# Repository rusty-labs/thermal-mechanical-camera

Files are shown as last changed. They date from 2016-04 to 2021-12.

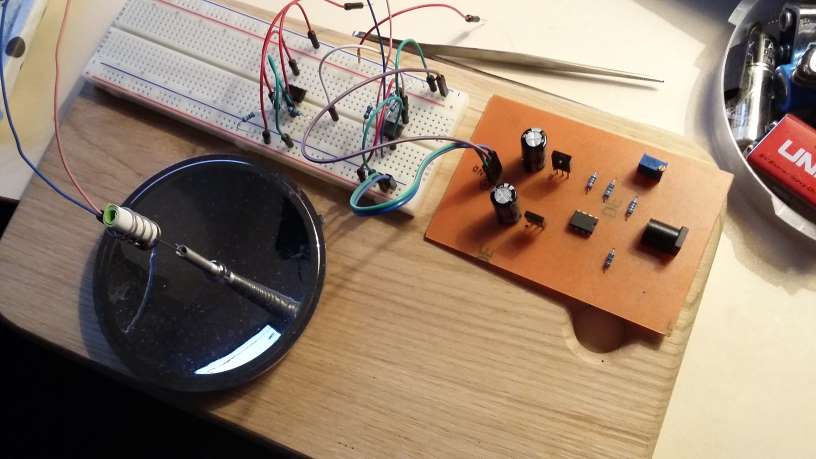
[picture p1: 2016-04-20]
scanner-photos/early_prototype001.jpg

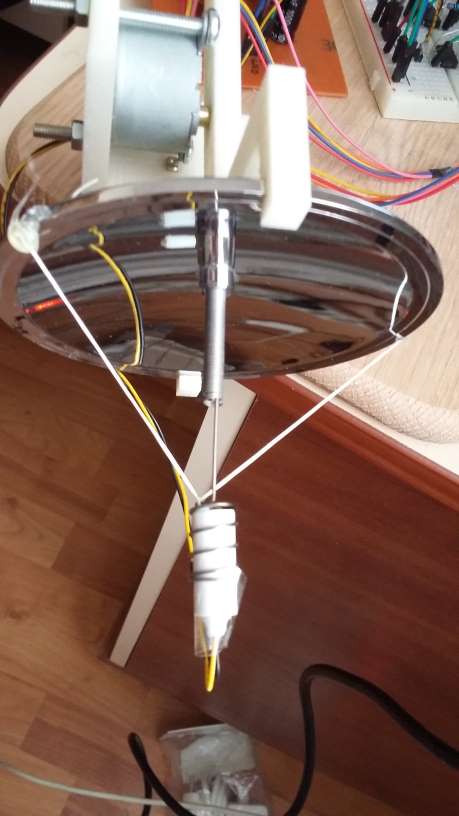
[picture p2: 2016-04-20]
scanner-photos/early_prototype002.jpg

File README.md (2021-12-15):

Building a cheap and simple thermal, mechanical camera.

Specs:
 Taking 400x200 image takes roughly 30 min. 

Hardware requirements:
 1. Metallized, parabolic mirror - "Survival Solar Lighter".
 2. 3D printed mounts for motors and mirror.
 3. Two stepper motors - 28byj-48, these motors will be used as bipolar motors.
 4. Two motor controllers based on L293D.
 5. Thermopile sensor:

   a) TS118, needs additional circuitry for amplifying the signal.
   
   b) MLX90614ESF, has circuitry inside so you don't need to create one (Recommended choice!).
   
 6. Amplifying circuitry, needed only if you're going to use TS118.
 7. Arduino
 8. MicroSD card module for arduino

Arduino code:

   a) For MLX90614ESF, this sensor returns temperature by I2C protocol.
   
   b) For TS118, this sensor returns analogue signal, which will be converted to temperature afterwards.

Overall cost - 25$.

Folders descriptions:

1. arduino\scanner - contains arduino code for running the scanning process.
2. circuits - contains circuits for stepper controller and signal amplification.
3. 3d-models - containts 3d models of mounts.
4. sample-images - contains thermal images.
5. scanner-photos - contains photos of a scanner.

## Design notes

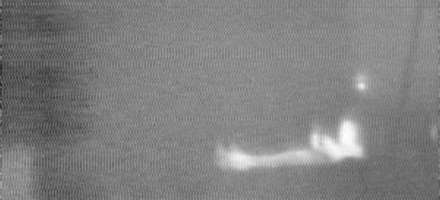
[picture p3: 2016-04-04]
sample-images/first image - reading book under lamp.jpg

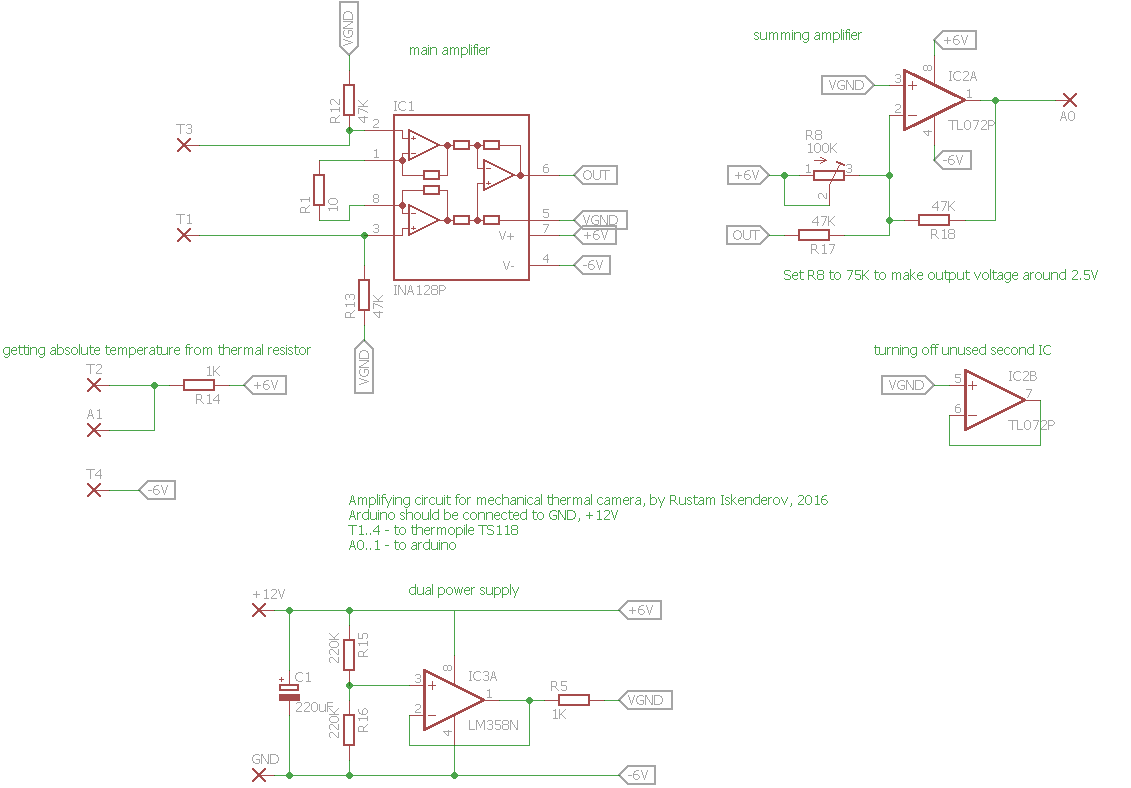
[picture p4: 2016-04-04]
circuits/Amplifying circuit for TS118.png

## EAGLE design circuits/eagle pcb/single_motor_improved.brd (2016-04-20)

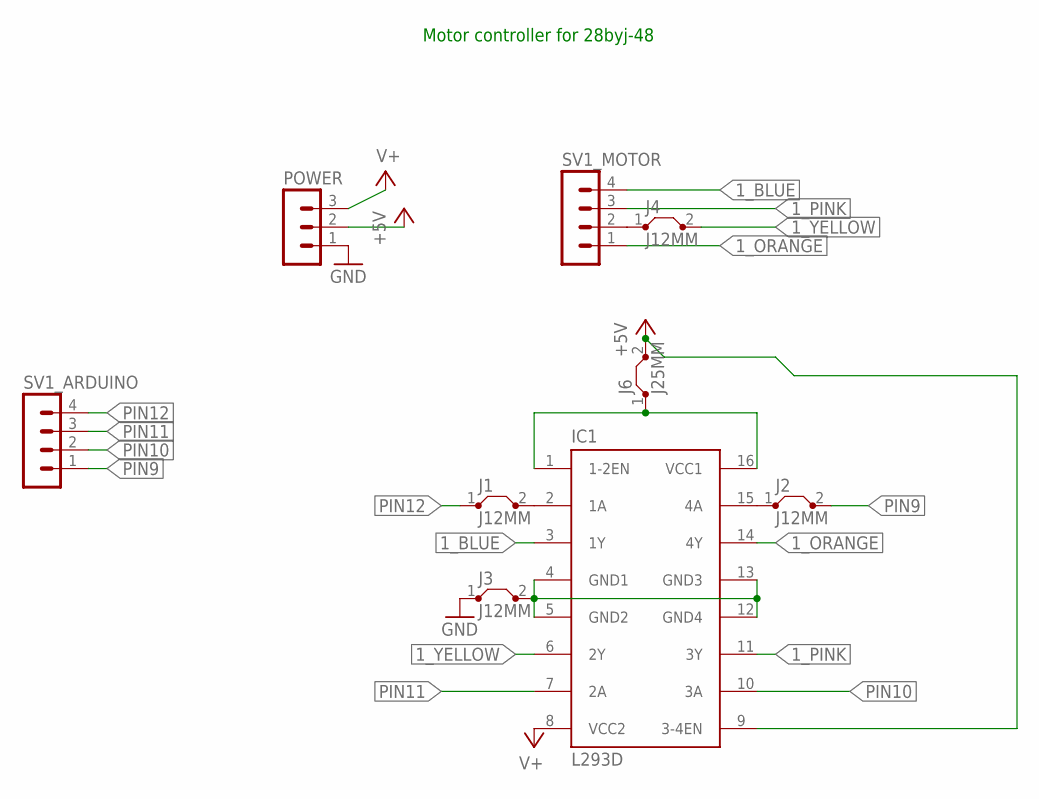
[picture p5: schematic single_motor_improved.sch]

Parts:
IC1: L293D; DIL16
J1, J2, J3, J4: J12MM; 12
J6: J25MM; 25
POWER: MA03-1
SV1_ARDUINO, SV1_MOTOR: MA04-1

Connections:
1_BLUE: IC1.3 (1Y), SV1_MOTOR.4
1_ORANGE: IC1.14 (4Y), SV1_MOTOR.1
1_PINK: IC1.11 (3Y), SV1_MOTOR.3
1_YELLOW: IC1.6 (2Y), J4.2
+5V: IC1.9 (3-4EN), J6.2, POWER.2
GND: J3.1, POWER.1
unnamed: IC1.2 (1A), J1.2
unnamed: IC1.15 (4A), J2.1
unnamed: IC1.1 (1-2EN), IC1.16 (VCC1), J6.1
unnamed: J4.1, SV1_MOTOR.2
unnamed: IC1.4 (GND1), IC1.5 (GND2), IC1.12 (GND4), IC1.13 (GND3), J3.2
PIN9: J2.2, SV1_ARDUINO.1
PIN10: IC1.10 (3A), SV1_ARDUINO.2
PIN11: IC1.7 (2A), SV1_ARDUINO.3
PIN12: J1.1, SV1_ARDUINO.4
V+: IC1.8 (VCC2), POWER.3

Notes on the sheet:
Motor controller for 28byj-48

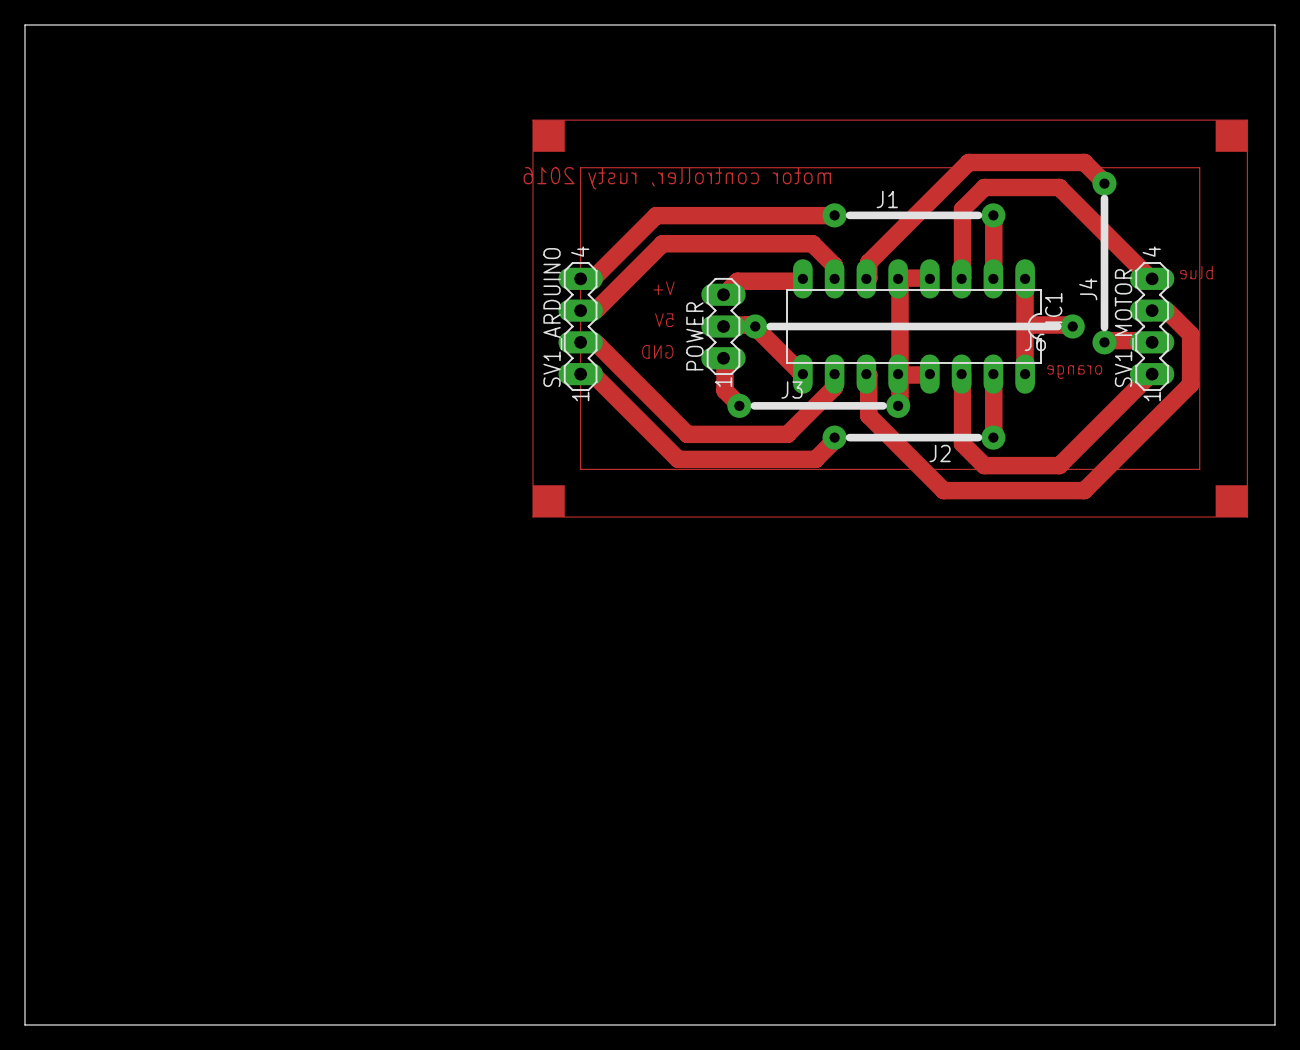
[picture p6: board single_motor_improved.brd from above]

Board: 2 copper layers, 100.0 x 80.0 mm, 9 parts (0 on the bottom side), 16 nets.

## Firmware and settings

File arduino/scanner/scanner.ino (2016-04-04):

#include <SPI.h>
#include <SD.h>

#define _DEBUG

#include "BasicMedianFilter.h"
#include "BitmapWriter.h"
#include "BasicStepper.h"


unsigned long last_time;
long time;

static const uint8_t SAMPLES_COUNT = 210;
BasicMedianFilter<uint16_t, SAMPLES_COUNT> m_temperature;


BasicStepper hStepper;
BasicStepper vStepper;
BmpWriter bmpWriter;

//const unsigned int H_SIZE = 4 * 110;
//const unsigned int V_SIZE = 4 * 50;

const unsigned int H_SIZE = 4 * 30;
const unsigned int V_SIZE = 4 * 20;

unsigned int v_pos = 0;
unsigned int h_pos = 0;
bool run_cycle = false;
bool finish_cycle = false;

unsigned long scanning_time = 0;


void setup()
{
  Serial.begin(9600);

  /*
  while (!Serial) {
    ; // wait for serial port to connect. Needed for Leonardo only
  }
  */
  if (!SD.begin(10)) {
    Serial.println("SD initialization failed!");
    return;
  }
  Serial.println("SD initialization done.");

  hStepper.init(5, 4, 3, 2);
  vStepper.init(A2, A3, A4, A5);

  hStepper.setDelay(0);
  vStepper.setDelay(0);
}


unsigned long time1;

uint16_t getTemperature()
{
  m_temperature.clear();

  uint32_t measurementTime = 20000 / SAMPLES_COUNT; // usec

  //  delayMicroseconds(18000);

  for (uint8_t i = 0; i < SAMPLES_COUNT; ++i)
  {
    uint32_t time1 = micros();
    m_temperature.add(analogRead(A0));

/*
    uint32_t time_spent = micros() - time1;

    if (time_spent < measurementTime)
    {
      delayMicroseconds(measurementTime - time_spent);
    }
*/
  }

  uint16_t _median;

  m_temperature.getMedian(_median);

    //m_temperature.getAverage(10, _median);
    //Serial.print("Median = ");
    //Serial.print(_median);
    //Serial.println(" ");


  return _median;
}

void startScanning()
{
  scanning_time = millis();

  char fileName[] = "output00.bmp";

  for (int i = 0; i < 100; ++i)
  {
    fileName[6] = i / 10 + '0';
    fileName[7] = i % 10 + '0';

    if (!SD.exists(fileName))
    {
      break;
    }
  }

  if (bmpWriter.create(fileName, H_SIZE, V_SIZE, 8) == false)
  {
    return;
  }

  bmpWriter.fillEmptyData();

  //delay(20000);

  run_cycle = true;
}


void stopScanning()
{
  finish_cycle = true;
}

void loop()
{
  /*
    time1 = micros();
    getTemperature();
    //Serial.println(micros()-time1);

    delay(300);

    return;
  */


  if (Serial.available())
  {
    int cmd = Serial.parseInt();

    switch (cmd)
    {
      case 0:
        stopScanning();
        break;

      case 2:
        vStepper.stepsAsync(4 * 5);
        vStepper.resetLastDir();
        break;

      case 3:
        vStepper.stepsAsync(-4 * 5);
        vStepper.resetLastDir();
        break;

      case 4:
        hStepper.stepsAsync(4 * 5);
        hStepper.resetLastDir();
        break;

      case 5:
        hStepper.stepsAsync(-4 * 5);
        hStepper.resetLastDir();
        break;

      case 9:
        startScanning();
        break;
    }

  }

  if (run_cycle)
  {
    if (hStepper.getState(BasicStepper::RUN) == false)
    {
      bmpWriter.flush();
      // moving to the next horizontal line
      vStepper.step(true);

      Serial.print("vertical pos: ");
      Serial.println(v_pos++);

      if (hStepper.getState(BasicStepper::LAST_DIR_FORWARD))
      {
        //going backward
        hStepper.stepsAsync(-H_SIZE);
        h_pos = H_SIZE - 1;
      } else
      {
        //going forward or stop

        h_pos = 0;

        if (finish_cycle)
        {
          bmpWriter.close();
          run_cycle = false;
          finish_cycle = false;
          vStepper.stepsAsync(-v_pos);
          v_pos = 0;
        } else
        { // new horizontal cycle

          if (v_pos > V_SIZE)
          { //scanning is finished
            bmpWriter.close();
            run_cycle = false;
            vStepper.stepsAsync(-v_pos);
            v_pos = 0;

            Serial.print("finished, scanning time, sec: ");
            Serial.println((millis() - scanning_time) / 1000);

          } else {
            hStepper.stepsAsync(H_SIZE);
          }

        }// end horizontal cycle

      }

    } else
    {
      if (v_pos <= V_SIZE)
      {
        uint32_t clr = (uint32_t(255) * getTemperature()) / 1023;

        // Serial.print("clr: ");
        // Serial.println(clr);

        bmpWriter.writePixel(h_pos, v_pos - 1, clr);

        if (hStepper.getState(BasicStepper::LAST_DIR_FORWARD))
        {
          ++h_pos;
        } else
        {
          --h_pos;
        }
      }


    }
  }

  hStepper.work();
  vStepper.work();
}

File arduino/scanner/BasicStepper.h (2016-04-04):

/*
 Created by Rustam Iskenderov, 2016
 For mechanical thermal imaging camera
*/


/*
 Simple way to control stepper motor
*/

class BasicStepper
{
  public:

    static const uint8_t RUN = 0x1;
    static const uint8_t LAST_DIR_FORWARD = 0x2;
    static const uint8_t LAST_DIR_BACKWARD = 0x4;

    void init(uint8_t pin0, uint8_t pin1, uint8_t pin2, uint8_t pin3)
    {
      _pin0 = pin0;
      _pin1 = pin1;
      _pin2 = pin2;
      _pin3 = pin3;

      reset();
      resetLastDir();

      _delay = 30000;

      pinMode(_pin0, OUTPUT);
      pinMode(_pin1, OUTPUT);
      pinMode(_pin2, OUTPUT);
      pinMode(_pin3, OUTPUT);

      digitalWrite(_pin0, LOW);
      digitalWrite(_pin1, LOW);
      digitalWrite(_pin2, LOW);
      digitalWrite(_pin3, LOW);
    }

    void setDelay(unsigned long delay)
    {
      _delay = delay;
    }

    void reset()
    {
      _coilIdx = 0;
      _steps = 0;
      setState(RUN, false);
    }

    void resetLastDir()
    {
      setState(LAST_DIR_FORWARD | LAST_DIR_BACKWARD, false);
    }


    void step(bool forward)
    {
      switch (_coilIdx) {
        case 0:
          digitalWrite(_pin0, LOW);
          digitalWrite(_pin1, HIGH);
          digitalWrite(_pin2, HIGH);
          digitalWrite(_pin3, LOW);
          break;
        case 1:
          digitalWrite(_pin0, LOW);
          digitalWrite(_pin1, HIGH);
          digitalWrite(_pin2, LOW);
          digitalWrite(_pin3, HIGH);
          break;
        case 2:
          digitalWrite(_pin0, HIGH);
          digitalWrite(_pin1, LOW);
          digitalWrite(_pin2, LOW);
          digitalWrite(_pin3, HIGH);
          break;
        case 3:
          digitalWrite(_pin0, HIGH);
          digitalWrite(_pin1, LOW);
          digitalWrite(_pin2, HIGH);
          digitalWrite(_pin3, LOW);
          break;
        default:
          park();
          break;
      }

      if (forward)
      {
        _coilIdx++;
      } else
      {
        _coilIdx--;
      }

      if (_coilIdx > 3)
      {
        _coilIdx = 0;
      }

      if (_coilIdx < 0)
      {
        _coilIdx = 3;
      }

      delayMicroseconds(_delay);
    }

    void stepsAsync(int16_t steps)
    {
      setState(RUN);
      _steps = steps;
      
      resetLastDir();
      
      if (steps > 0)
      {
        setState(LAST_DIR_FORWARD);
      } else
      {
        setState(LAST_DIR_BACKWARD);
      }
    }

    void work()
    {
      if (getState(RUN))
      {
        int8_t dir = _steps > 0 ? -1 : 1;

        if (_steps != 0)
        {
          step(_steps > 0 ? true : false);
          _steps += dir;
        } else
        {
          setState(RUN, false);
          park();
        }
      }
    }

    void setState(uint8_t state, bool set = true)
    {
      if (set)
      {
        _states |= state;
      } else
      {
        _states &= ~state;
      }
    }

    bool getState(uint8_t state)
    {
      return (_states & state) != 0;
    }

    void park()
    {
      digitalWrite(_pin0, LOW);
      digitalWrite(_pin1, LOW);
      digitalWrite(_pin2, LOW);
      digitalWrite(_pin3, LOW);
      reset();
    }

  private:
    uint8_t _pin0, _pin1, _pin2, _pin3;
    int8_t _coilIdx;
    int16_t _steps;
    uint8_t _states;
    uint16_t _delay;
};

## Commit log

2016-04-04 added circuit for TS118
2016-04-04 added sample image
2016-04-20 added photos
    [amplification.sch, single_motor_improved.brd, single_motor_improved.sch]
